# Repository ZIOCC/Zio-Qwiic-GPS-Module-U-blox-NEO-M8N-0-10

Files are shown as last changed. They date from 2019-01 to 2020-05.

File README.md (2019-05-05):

# Zio Qwiic GPS Module (U-blox NEO-M8N-0-10)

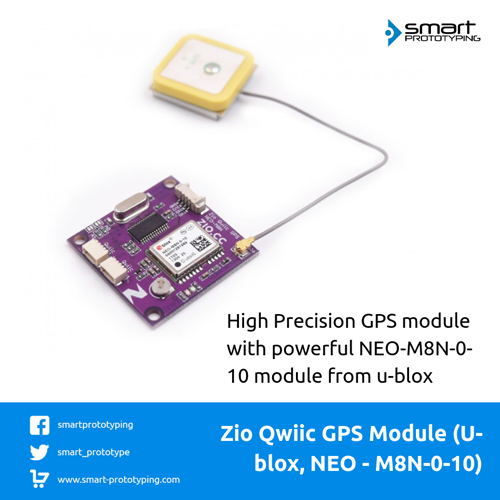
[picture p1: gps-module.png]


> This product can be available for purchase [here](https://www.smart-prototyping.com/Zio-Qwiic-GPS-Module-U-blox-NEO-M8N-0-10).

#### Description

GPS is the most interesting part for makers, with GPS, you can know where you are, or state the location of the object that you are tracking. 

This is a high precision GPS module that includes a powerful NEO-M8N-0-10 module from u-blox. 

The NEO-M8N module is based on the u-blox M8 GNSS (GPS, GLONASS, BeiDou, QZSS, SBAS and Galileo-ready1) engine that provides high sensitivity and minimal acquisition times while maintaining low system power.

We used a SC16IS752IPW to convert the module’s data from UART to I2C (Qwiic connectors),  so that you can use [Qwiic cable](https://www.smart-prototyping.com/zio-cables) to quickly connect the GPS module to any other Qwiic devices.
We also breakout the UART port to a 1.27mm terminal connector, just in case you want to use UART port directly.  

We’ve even included a rechargeable backup battery to help keep the latest module configuration and satellite data available for up to two weeks. This battery helps to ‘warm-start’ the module, decreasing the time-to-first-fix dramatically. It also features a survey-in mode allowing the module to become a base station and produce RTCM 3.x correction data (as opposed to the previous version of the module which is not able to produce RTCM data).

We also offer you a tested GPS antenna for the module, you can just plug it into the IPX connector on the board. The antenna is required when you get it running. Note: The antenna needs to face towards the top.

#### Specification

* Voltage: 3.3V
* Horizontal position accuracy: 2.5 m
* Heading accuracy: 0.3 degrees
* Velocity accuracy: 0.05 m/s
* Time-To-First-Fix: 27 - 30s (cold), 1s (hot)
* Interface: I2C and UART

* IC:SC16IS752
* address: 0x4D, 0x4C, 0x49, 0x48 (Default: 0x4D)
* Dimension: 35.5 x 35.8mm
* Weight: 7.8g

#### Links

* [PCB Source file](https://github.com/ZIOCC/Zio-Qwiic-GPS-Module-U-blox-NEO-M8N-0-10/tree/master/EAGLE)
* [PCB schematic](https://github.com/ZIOCC/Zio-Qwiic-GPS-Module-U-blox-NEO-M8N-0-10/blob/master/zio%20qwiic%20gps%20module%20ublox%20schematic%20pdf.pdf)
* [Demo code](https://github.com/toskyRocker/Arduino_Parser_Ublox_Neo_M8N)
* [GPS module NEO-M8N-0-10 datasheet](https://www.u-blox.com/sites/default/files/NEO-M8-FW3_DataSheet_%28UBX-15031086%29.pdf)

###### About Zio
> Zio is a new line of open sourced, compact, and grid layout boards, fully integrated for Arduino and Qwiic ecosystem. Designed ideally for wearables, robotics, small-space limitations or other on the go projects. Check out other awesome Zio products [here](https://www.smart-prototyping.com/Zio).

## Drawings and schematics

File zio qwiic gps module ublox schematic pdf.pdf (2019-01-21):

+3V3 1K ±1%

A

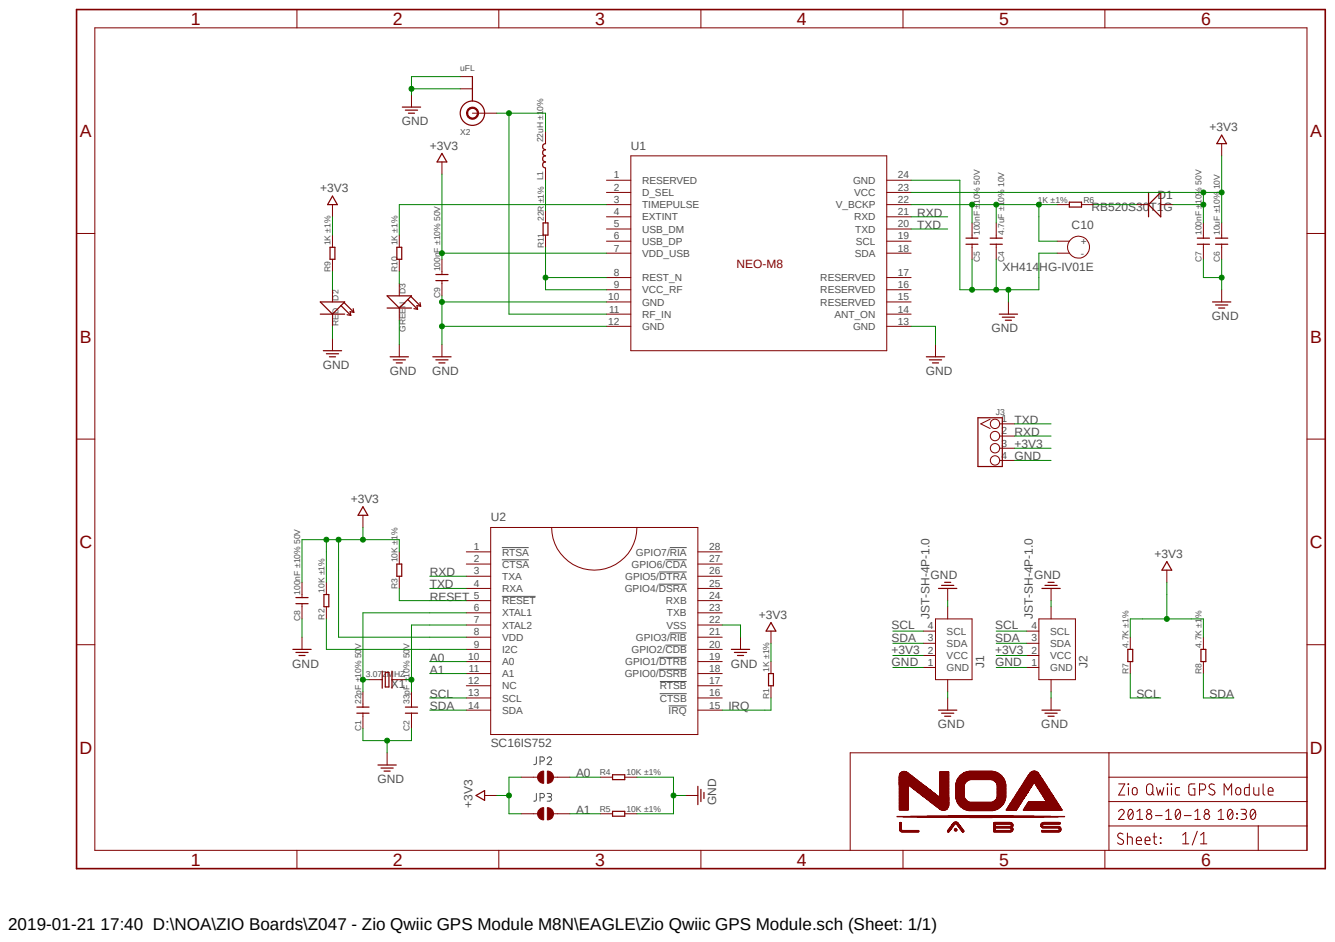
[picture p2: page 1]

EXTINT 4 USB_DM 5 USB_DP 6 VDD_USB 7

REST_N 8

I2C 9
A0 10 A1 11 NC 12 SCL 13

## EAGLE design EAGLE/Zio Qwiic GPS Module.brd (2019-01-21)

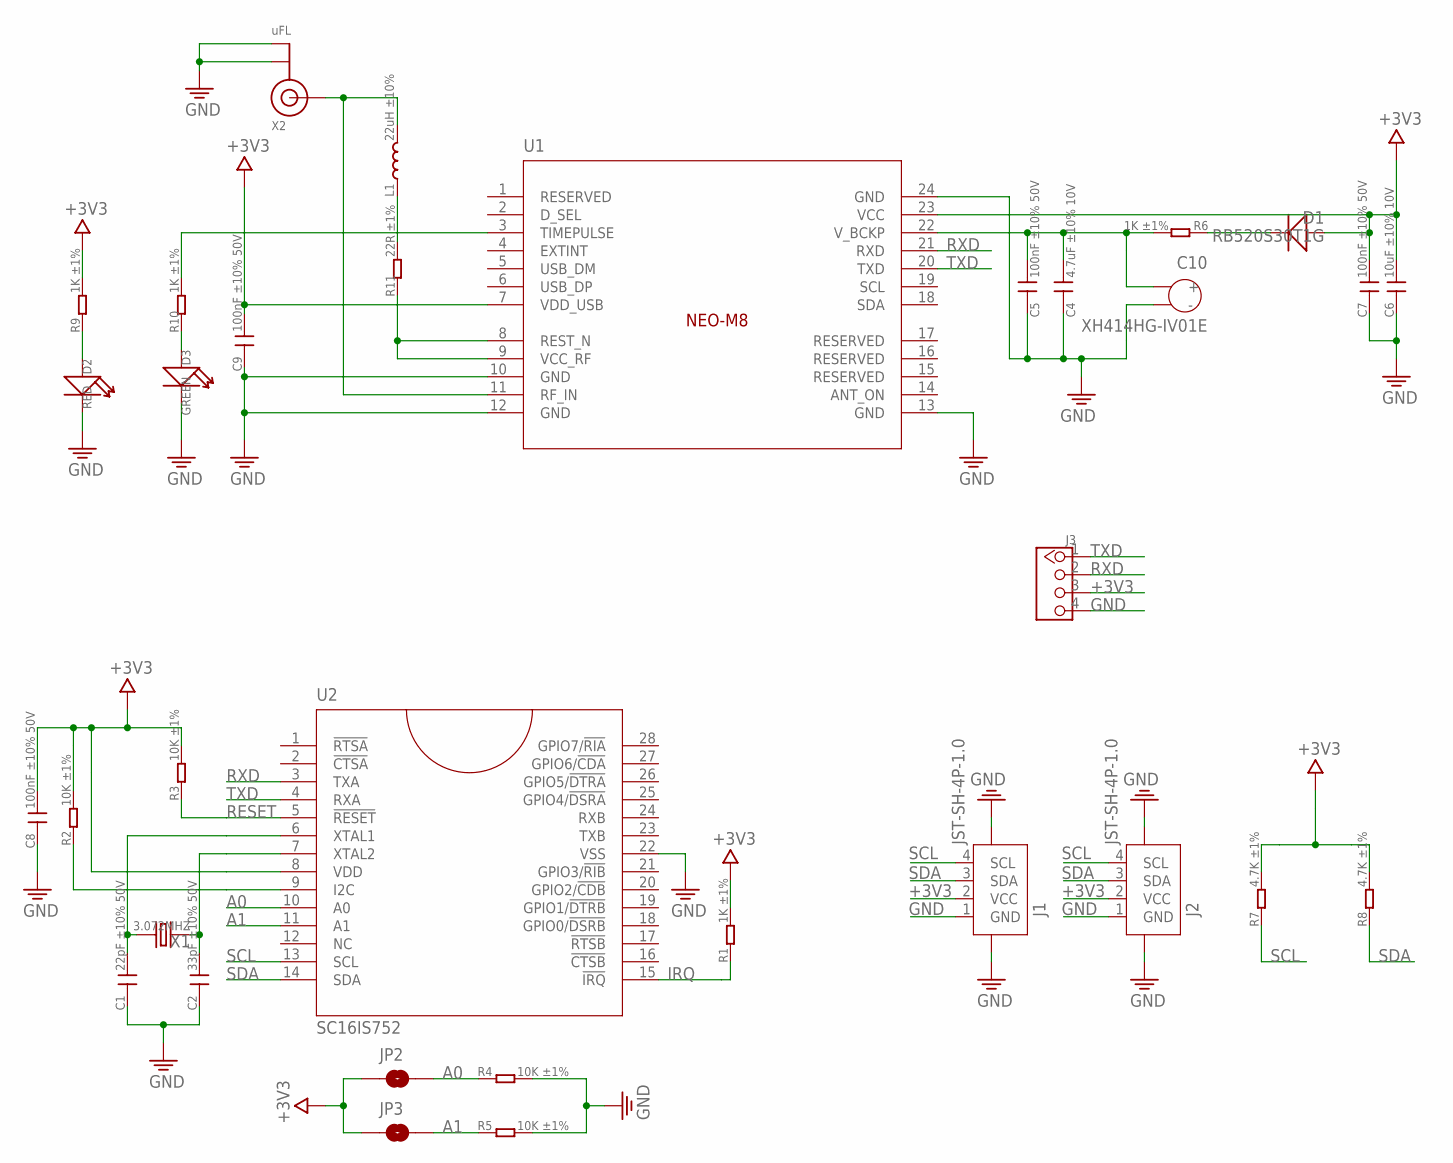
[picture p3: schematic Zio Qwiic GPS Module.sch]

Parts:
C1: 22pF ±10% 50V; C0603
C2: 33pF ±10% 50V; C0603
C4: 4.7uF ±10% 10V; C0603
C5, C7, C8, C9: 100nF ±10% 50V; C0603
C6: 10uF ±10% 10V; C0603
C10: XH414HG-IV01E
D1: RB520S30T1G; SOD523
D2: RED; LED-0603
D3: GREEN; LED-0603
J1, J2: JST-SH-4P-1.0; JST-SH-4P
J3: HEADER-4P-1.25-SMD; 4PIN_SMD
JP2, JP3: JUMPER-SMT_2_NC_PASTE_NOCREM; SMT-JUMPER_2_NC_PASTE_SILK_NOCREM
L1: 22uH ±10%; L0603
R1, R6, R9, R10: 1K ±1%; R0603
R2, R3, R4, R5: 10K ±1%; R0603
R7, R8: 4.7K ±1%; R0603
R11: 22R ±1%; R0603
U1: NEO-M8N
U2: SC16IS752; TSSOP28
X1: 3.072MHZ; HC49/S
X2: uFL; U.FL

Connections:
+3V3: C6.2, C7.2, C8.2, C9.2, D1.+, J1.2 (VCC), J2.2 (VCC), J3.3, JP2.1, JP3.1, R1.2, R2.2, R3.2, R7.2, R8.2, R9.2, U1.7 (VDD_USB), U1.23 (VCC), U2.8 (VDD)
A0: JP2.2, R4.1, U2.10 (A0)
A1: JP3.2, R5.1, U2.11 (A1)
GND: C1.1, C2.1, C4.1, C5.1, C6.1, C7.1, C8.1, C9.1, C10.-, D2.-, D3.-, J1.1 (GND), J1.NC1 (5), J1.NC2 (6), J2.1 (GND), J2.NC1 (5), J2.NC2 (6), J3.4, R4.2, R5.2, U1.10 (GND), U1.12 (GND), U1.13 (GND), U1.24 (GND), U2.22 (VSS), X2.1 (GND), X2.2 (GND)
IRQ: R1.1, U2.15 (!IRQ)
unnamed: D1.-, R6.1
unnamed: D2.+, R9.1
unnamed: R10.2, U1.3 (TIMEPULSE)
unnamed: D3.+, R10.1
unnamed: R2.1, U2.9 (I2C)
unnamed: C4.2, C5.2, C10.+, R6.2, U1.22 (V_BCKP)
unnamed: C2.2, U2.7 (XTAL2), X1.1
unnamed: C1.2, U2.6 (XTAL1), X1.2
unnamed: R11.1, U1.8 (REST_N), U1.9 (VCC_RF)
unnamed: L1.1, R11.2
unnamed: L1.2, U1.11 (RF_IN), X2.3 (SIGNAL)
RESET: R3.1, U2.5 (!RESET)
RXD: J3.2, U1.21 (RXD), U2.3 (TXA)
SCL: J1.4 (SCL), J2.4 (SCL), R7.1, U2.13 (SCL)
SDA: J1.3 (SDA), J2.3 (SDA), R8.1, U2.14 (SDA)
TXD: J3.1, U1.20 (TXD), U2.4 (RXA)

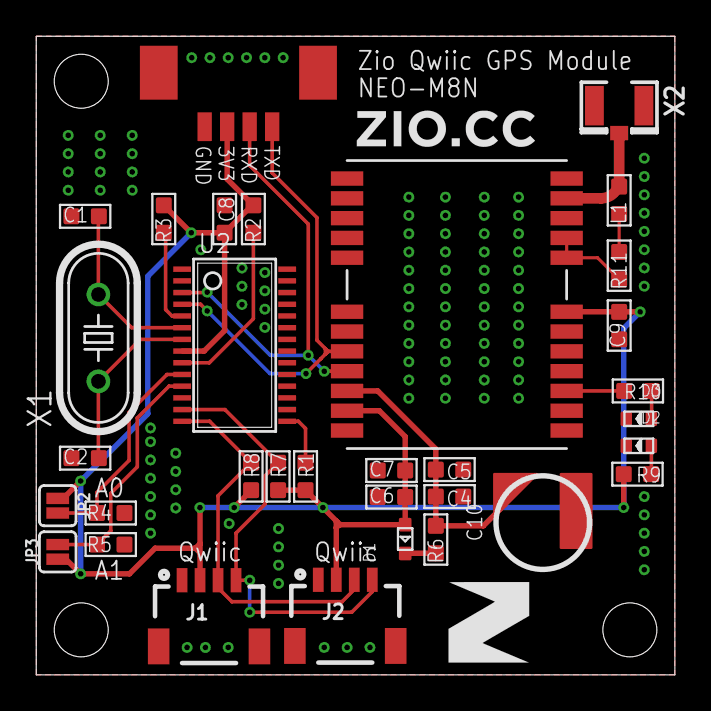
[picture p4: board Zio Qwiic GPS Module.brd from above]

Board: 2 copper layers, 35.5 x 35.5 mm, 35 parts (0 on the bottom side), 21 nets.

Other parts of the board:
U$7: 7MM
U$8: 2MM

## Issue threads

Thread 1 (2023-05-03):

Build Of Materials (BOM) List

KingVickyRaj, 2023-05-03:
Hi,

I would like to know that since this is specific product is coming under the open-source category and you have provided with the gerber files and all other required details for the PCB to be printed out. I would like to know whether I could get the BOM List of this Board with the specific manufacturer part numbers with them so that I could use it in my project.
The reason why I am asking for this is because the components being used in this circuit have different impedance characteristics like the  inductor being used and it varies with frequency. I had problem some time back when dealing with GPS and the inductor even though it has the same inductance values, the impedance characteristics were far apart and this I think will be an issue in such a board working with GPS.
So I would like to ask if you could provide with a BOM List for the components used in this PCB along with their manufacturer part number so that the PCB files can be made use of.

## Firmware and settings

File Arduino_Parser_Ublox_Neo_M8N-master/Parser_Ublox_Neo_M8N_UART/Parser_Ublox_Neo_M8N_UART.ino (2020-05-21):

/* Andrea Toscano
Universita' degli Studi di Milano

Sample script - Reading some info from U-Blox Neo M8N GPS/GLONASS
*/
#include <SoftwareSerial.h>
#include "Ublox.h"
#define SERIAL_BAUD 115200
#define GPS_BAUD 9600
#define N_FLOATS 4
SoftwareSerial ss(4, 3);
Ublox M8_Gps;
// Altitude - Latitude - Longitude - N Satellites
float gpsArray[N_FLOATS] = {0, 0, 0, 0};

void setup() {
   Serial.begin(SERIAL_BAUD);
   ss.begin(GPS_BAUD);
   pinMode(LED_BUILTIN, OUTPUT);
}

void loop() {
   if(!ss.available())
		return;

  while(ss.available()){
        char c = ss.read();
         if (M8_Gps.encode(c)) {
          gpsArray[0] = M8_Gps.altitude;
          gpsArray[1] = M8_Gps.latitude;
          gpsArray[2] = M8_Gps.longitude; 
          gpsArray[3] = M8_Gps.sats_in_use;
        }
  }
  for(byte i = 0; i < N_FLOATS; i++) {
    Serial.print(gpsArray[i], 6);Serial.print(" ");
  }
  Serial.println("");
}

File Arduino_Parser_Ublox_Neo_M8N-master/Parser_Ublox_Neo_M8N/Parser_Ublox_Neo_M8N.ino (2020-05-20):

/* Andrea Toscano
Universita' degli Studi di Milano

Sample script - Reading some info from U-Blox Neo M8N GPS/GLONASS
*/
#include <Wire.h>
#include "Ublox.h"
#include <Adafruit_GFX.h>
#include <Adafruit_SSD1306.h>
#include "SC16IS752.h"
#define SERIAL_BAUD 9600
#define GPS_BAUD 9600
#define N_FLOATS 4
#define Address 0x4D

#define OLED_RESET 4
Adafruit_SSD1306 display(OLED_RESET);

Ublox M8_Gps;
SC16IS752 SC16IS752;
// Altitude - Latitude - Longitude - N Satellites
float gpsArray[N_FLOATS] = {0, 0, 0, 0};
char Buffer[100];
uint8_t i=0,num=0;
void setup() {
    SC16IS752.begin(Address,true);
    SC16IS752.setup(CHANA,BAUD_9600,UART_8N1);
    
    SC16IS752.setGPIODir(0xFF);
   Serial.begin(SERIAL_BAUD);
   pinMode(13, OUTPUT);
//   display.begin(SSD1306_SWITCHCAPVCC, 0x3C);  // initialize with the I2C addr 0x3C (for the 128x32)
//   display.clearDisplay();
 
}

void loop() {
 if(SC16IS752.checkRxLevel(CHANA)>0)
 {
 num=SC16IS752.readUART_Array(CHANA,Buffer);
    for(i=0;i<num;i++)
    {
      char c=Buffer[i];
     if (M8_Gps.encode(c)) {
            gpsArray[0] = M8_Gps.altitude;
            gpsArray[1] = M8_Gps.latitude;
            gpsArray[2] = M8_Gps.longitude; 
            gpsArray[3] = M8_Gps.sats_in_use;
       }
      }
      for(i=0;i<num;i++)
      {
        Buffer[i]=0;
      }
  }
if(gpsArray[3]>0)
{
  for(byte i = 0; i < N_FLOATS; i++) {
    Serial.print(gpsArray[i], 6);Serial.print(" ");
  }
//  display.setTextSize(2);
//  display.setTextColor(WHITE);
//  display.setCursor(0,0);
//  display.clearDisplay();
//  display.print("Star:");
//  display.print(gpsArray[3]);
//  display.display();
  for(byte i = 0; i < N_FLOATS; i++)
  {
    gpsArray[i]=0;
    }
  digitalWrite(13,HIGH);
  Serial.println("");
}

}

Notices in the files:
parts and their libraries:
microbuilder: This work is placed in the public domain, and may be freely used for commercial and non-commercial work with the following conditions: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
